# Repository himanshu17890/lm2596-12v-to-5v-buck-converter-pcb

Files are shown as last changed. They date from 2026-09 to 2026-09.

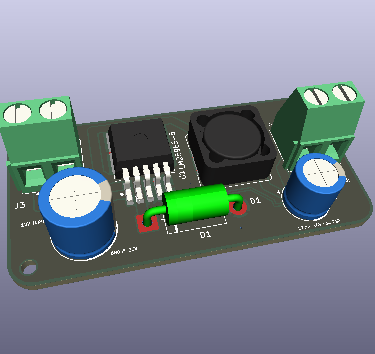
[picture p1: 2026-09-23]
LM2596_Buck_Converter.png

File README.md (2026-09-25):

# LM2596 12 V to 5 V Buck Converter PCB

A two-layer PCB for converting a 12 V DC input into a regulated 5 V DC output using an LM2596S-5 switching regulator.



## Features

- 12 V DC input through a 2-pin screw terminal
- Fixed 5 V DC output through a 2-pin screw terminal
- LM2596S-5 buck regulator
- Up to 3 A regulator rating; final usable current depends on cooling, copper area, and component ratings
- Two-layer layout with F.Cu and B.Cu ground pours
- Two M2 mounting holes and rounded board corners

## Connections

| Terminal | Pin 1 | Pin 2 |
|---|---|---|
| J3 input | IN+ / +12 V | IN- / GND |
| J4 output | OUT+ / +5 V | OUT- / GND |

Use DC input only. Do **not** connect AC mains. Confirm the output is approximately 5.0 V with a multimeter before connecting a load, and never reverse the input polarity.

## Main Components

| Reference | Component | Value / requirement |
|---|---|---|
| U1 | LM2596S-5 | Fixed 5 V buck regulator, TO-263-5 package |
| C1 | Polarized electrolytic capacitor | 680 uF, 25 V |
| C2 | Low-ESR polarized electrolytic capacitor | 220 uF, 10 V |
| L1 | Power inductor | 33 uH, at least 3 A saturation current |
| D1 | Schottky diode | 1N5824 or equivalent |
| J3, J4 | Screw terminals | 2-pin, 5.00 mm pitch |

## Project Files

Place the KiCad files in this repository root:

- `LM2596_Buck_Converter.kicad_pro`
- `LM2596_Buck_Converter.kicad_sch`
- `LM2596_Buck_Converter.kicad_pcb`







## Simulation

The design was verified in KiCad's built-in ngspice simulator using Texas Instruments' official transient SPICE model for the LM2596-5.0 (`LM2596_5P0_TRANS.LIB`, released by TI's Analog eLab Design Center), loaded via U1's Simulation Model dialog in place of a generic model.

**Setup:** 12 V input, 33 uH inductor, 220 uF output capacitor, 5 ohm (1 A) resistive load. Transient analysis, 50 ns time step, initial conditions enabled (`uic`) so the simulation starts from 0 V rather than an artificial DC operating point.

**Startup and settling — output ramps from 0 V through a stepped soft-start to ~5.0 V in about 1 ms:**

Startup and settling

**Zoomed output ripple (3.25-3.41 ms window):**

Output ripple

**Results:**

- Output regulates to **~5.0 V**, matching the datasheet's 4.8-5.2 V spec at this load.
- Soft-start ramp from 0 V to regulation in **~1 ms**, matching the LM2596's internal soft-start behavior.
- With an ideal (zero-ESR) output capacitor, the loop rings at roughly 15 kHz with ~80 mV peak-to-peak swing, as shown above. Adding a realistic ESR of 0.05-0.1 ohm in series with C2 (representative of a genuine low-ESR electrolytic) damps this to **~20 mV**, confirming the datasheet's note that very low output-capacitor ESR can destabilize the feedback loop.

- 


**Model file:** [`sim/LM2596_5P0_TRANS.LIB`](sim/LM2596_5P0_TRANS.LIB)
See [`sim/SIMULATION_RESULTS.md`](sim/SIMULATION_RESULTS.md) for the full write-up, pin mapping, and settings.

> The model is TI's own release, provided "as is" with no warranty (see header comments in the file). It is not officially validated for ngspice, but ran without errors under ngspice's PSpice/LTspice compatibility mode.

## Manufacturing Checklist

1. Run ERC and DRC with zero errors.
2. Inspect the board in KiCad 3D Viewer.
3. Verify diode polarity, capacitor polarity, connector labels, and U1 orientation.
4. Verify every selected footprint matches the purchased component datasheet.
5. Generate Gerber and drill files from KiCad's Plot dialog.

## License

This project is provided for learning and personal use. Review the design independently before manufacturing or using it with valuable equipment.

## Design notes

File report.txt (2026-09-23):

Info: Processing symbol 'C1:Capacitor_THT:CP_Radial_D10.0mm_P5.00mm'.
Info: Processing symbol 'J3:TerminalBlock_Phoenix:TerminalBlock_Phoenix_MKDS-1,5-2_1x02_P5.00mm_Horizontal'.
Info: Processing symbol 'C2:Capacitor_THT:CP_Radial_D8.0mm_P3.50mm'.
Info: Processing symbol 'D1:Diode_THT:D_DO-201AD_P15.24mm_Horizontal'.
Info: Processing symbol 'J4:TerminalBlock_Phoenix:TerminalBlock_Phoenix_MKDS-1,5-2_1x02_P5.00mm_Horizontal'.
Info: Processing symbol 'L1:Inductor_SMD:L_Bourns_SRR1260'.
Info: Processing symbol 'U1:Package_TO_SOT_SMD:TO-263-5_TabPin3'.
Updated C1 symbol association from  to /0ac7c295-e850-41f9-afc6-6db656250fa2.
Updated C1 fields.
Updated C1 sheetname to '/'.
Updated C1 sheetfile to 'LM2596_Buck_Converter.kicad_sch'.
Updated C1 footprint filters to 'CP_*'.
Add net +12V.
Connected C1 pin 1 to +12V.
Add net GND.
Connected C1 pin 2 to GND.
Updated C1 unit metadata.
Added C2 (footprint 'Capacitor_THT:CP_Radial_D8.0mm_P3.50mm').
Changed REF** reference designator to C2.
Changed C2 value from CP_Radial_D8.0mm_P3.50mm to 220uF 10V Low ESR.
Updated C2 symbol association from  to /bcc400e6-14d5-4933-ad8a-5b8f2b3d2013.
Updated C2 fields.
Updated C2 sheetname to '/'.
Updated C2 sheetfile to 'LM2596_Buck_Converter.kicad_sch'.
Updated C2 footprint filters to 'CP_*'.
Add net +5V.
Connected C2 pin 1 to +5V.
Connected C2 pin 2 to GND.
Updated C2 unit metadata.
Added D1 (footprint 'Diode_THT:D_DO-201AD_P15.24mm_Horizontal').
Changed REF** reference designator to D1.
Changed D1 value from D_DO-201AD_P15.24mm_Horizontal to D_Schottky.
Updated D1 symbol association from  to /a81eedd1-ab4e-4fa0-9138-1fd4981f2f24.
Updated D1 fields.
Updated D1 sheetname to '/'.
Updated D1 sheetfile to 'LM2596_Buck_Converter.kicad_sch'.
Updated D1 footprint filters to 'TO-???* *_Diode_* *SingleDiode* D_*'.
Add net Net-(D1-K).
Connected D1 pin 1 to Net-(D1-K).
Connected D1 pin 2 to GND.
Updated D1 unit metadata.
Added J3 (footprint 'TerminalBlock_Phoenix:TerminalBlock_Phoenix_MKDS-1,5-2_1x02_P5.00mm_Horizontal').
Changed REF** reference designator to J3.
Changed J3 value from TerminalBlock_Phoenix_MKDS-1,5-2_1x02_P5.00mm_Horizontal to Conn_01x02.
Updated J3 symbol association from  to /9047c72f-d596-4f4e-b07e-ea304f9d36cc.
Updated J3 fields.
Updated J3 sheetname to '/'.
Updated J3 sheetfile to 'LM2596_Buck_Converter.kicad_sch'.
Updated J3 footprint filters to 'Connector*:*_1x??_*'.
Connected J3 pin 1 to +12V.
Connected J3 pin 2 to GND.
Updated J3 unit metadata.
Added C1 (footprint 'Capacitor_THT:CP_Radial_D10.0mm_P5.00mm').
Added J4 (footprint 'TerminalBlock_Phoenix:TerminalBlock_Phoenix_MKDS-1,5-2_1x02_P5.00mm_Horizontal').
Changed REF** reference designator to J4.
Changed J4 value from TerminalBlock_Phoenix_MKDS-1,5-2_1x02_P5.00mm_Horizontal to Conn_01x02.
Updated J4 symbol association from  to /3a92cf1b-8982-4e3b-b165-ed0cf6522ced.
Updated J4 fields.
Updated J4 sheetname to '/'.
Updated J4 sheetfile to 'LM2596_Buck_Converter.kicad_sch'.
Updated J4 footprint filters to 'Connector*:*_1x??_*'.
Connected J4 pin 2 to GND.
Connected J4 pin 1 to +5V.
Updated J4 unit metadata.
Changed REF** reference designator to C1.
Added L1 (footprint 'Inductor_SMD:L_Bourns_SRR1260').
Changed REF** reference designator to L1.
Changed L1 value from L_Bourns_SRR1260 to L.
Updated L1 symbol association from  to /3353ad08-bed3-489c-b2b1-2c32728b39ec.
Updated L1 fields.
Updated L1 sheetname to '/'.
Updated L1 sheetfile to 'LM2596_Buck_Converter.kicad_sch'.
Updated L1 footprint filters to 'Choke_* *Coil* Inductor_* L_*'.
Connected L1 pin 1 to Net-(D1-K).
Connected L1 pin 2 to +5V.
Updated L1 unit metadata.
Changed C1 value from CP_Radial_D10.0mm_P5.00mm to 680uF 25V.
Added U1 (footprint 'Package_TO_SOT_SMD:TO-263-5_TabPin3').
Changed REF** reference designator to U1.
Changed U1 value from TO-263-5_TabPin3 to LM2596S-5.
Updated U1 symbol association from  to /224b4588-2d89-42ec-bae6-352861aeed91.
Updated U1 fields.
Updated U1 sheetname to '/'.
Updated U1 sheetfile to 'LM2596_Buck_Converter.kicad_sch'.
Updated U1 footprint filters to 'TO?263*'.
Connected U1 pin 1 to +12V.
Connected U1 pin 2 to Net-(D1-K).
Connected U1 pin 5 to GND.
Connected U1 pin 3 to GND.
Connected U1 pin 4 to +5V.
Connected U1 pin 3 to GND.
Updated U1 unit metadata.

Info: Total warnings: 0, errors: 0.

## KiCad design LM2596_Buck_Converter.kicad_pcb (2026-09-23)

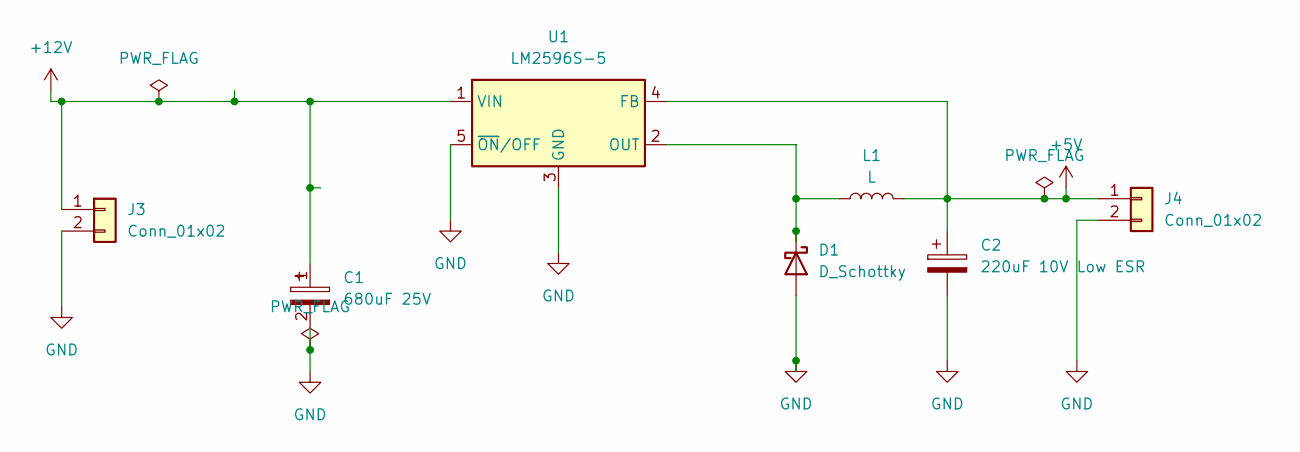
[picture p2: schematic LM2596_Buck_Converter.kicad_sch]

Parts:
C1: 680uF 25V; CP_Radial_D10.0mm_P5.00mm
C2: 220uF 10V Low ESR; CP_Radial_D8.0mm_P3.50mm
D1: D_Schottky; D_DO-201AD_P15.24mm_Horizontal
J3, J4: Conn_01x02; TerminalBlock_Phoenix_MKDS-1,5-2_1x02_P5.00mm_Horizontal
L1: L; L_Bourns_SRR1260
U1: LM2596S-5; TO-263-5_TabPin3

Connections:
+5V: C2.1, J4.1, L1.2, U1.4 (FB)
+12V: C1.1, J3.1, U1.1 (VIN)
GND: C1.2, C2.2, D1.2 (A), J3.2, J4.2, U1.3 (GND), U1.5 (~ON/OFF)
unnamed: D1.1 (K), L1.1, U1.2 (OUT)

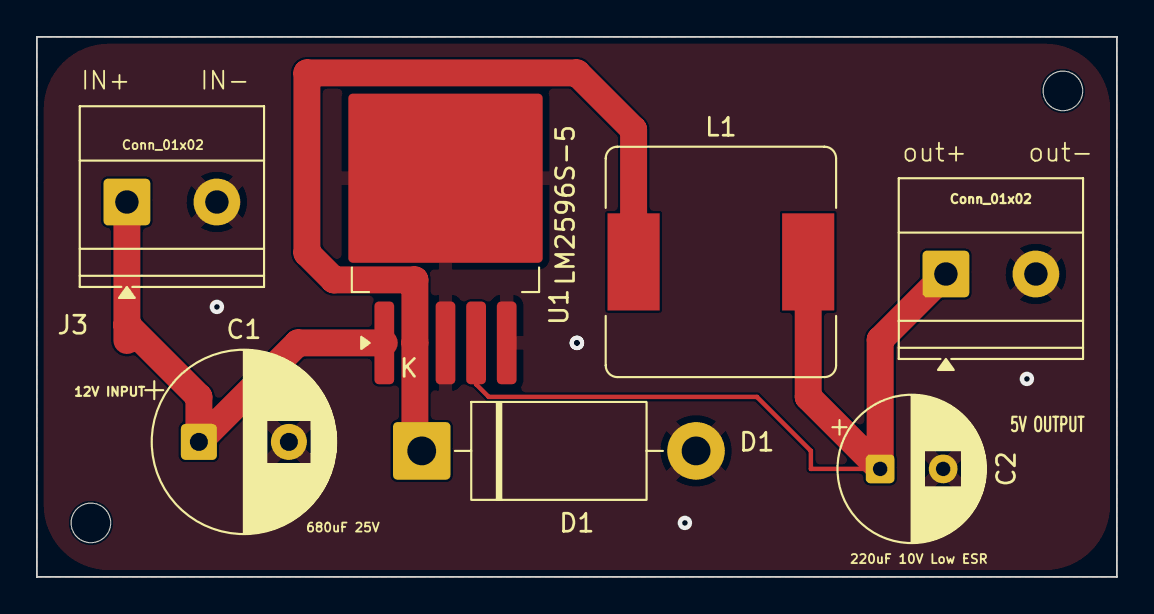
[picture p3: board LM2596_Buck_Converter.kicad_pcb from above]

Board: 2 copper layers, 60.0 x 30.0 mm, 7 parts (0 on the bottom side), 4 nets.

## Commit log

2026-09-23 Initial commit: LM2596 buck converter PCB
    [LM2596_Buck_Converter.kicad_pcb, LM2596_Buck_Converter.kicad_sch]
2026-09-23 Add README for LM2596 Buck Converter PCB
    Added detailed documentation for the LM2596 buck converter PCB, including features, connections, main components, project files, and a manufacturing checklist.
